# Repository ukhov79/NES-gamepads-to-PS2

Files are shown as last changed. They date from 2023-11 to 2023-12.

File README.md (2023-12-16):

# NES gamepads via PS2 interface
Connecting 8-bit NES gamepads to retrocomputer emulators or old PC via the PS2 interface

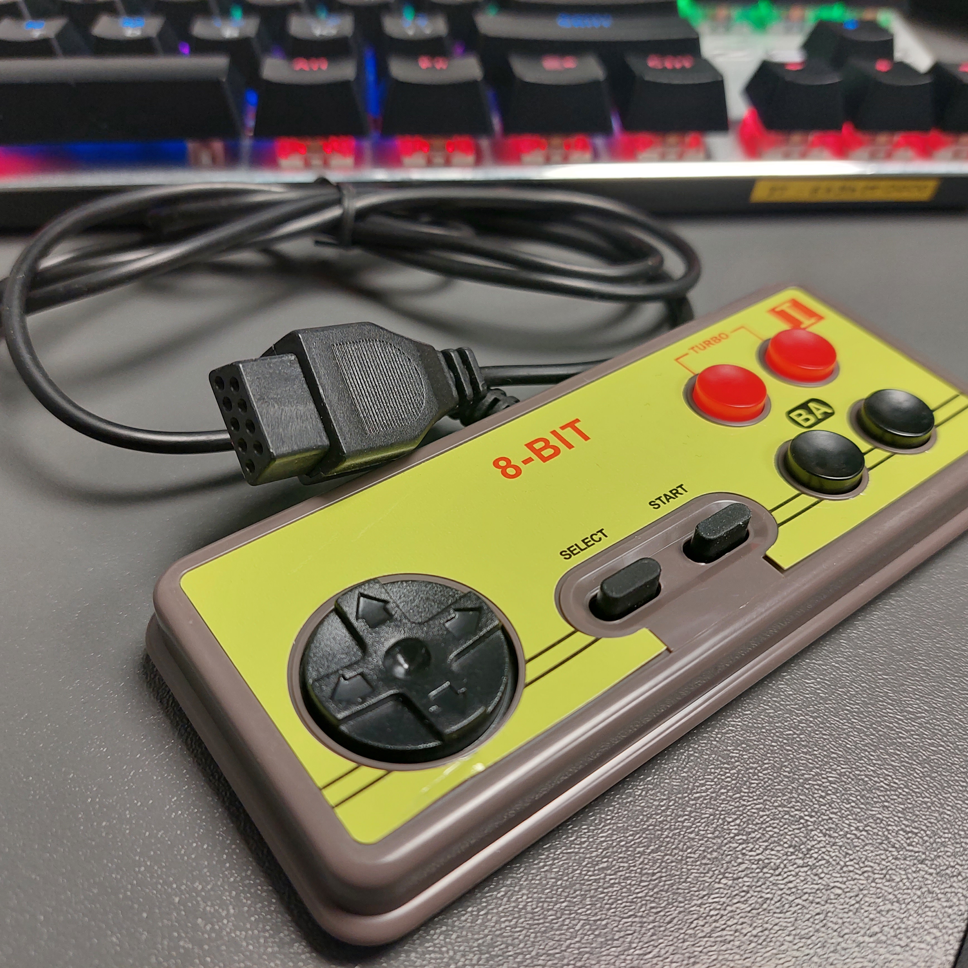
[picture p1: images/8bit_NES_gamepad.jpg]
NES Gamepad
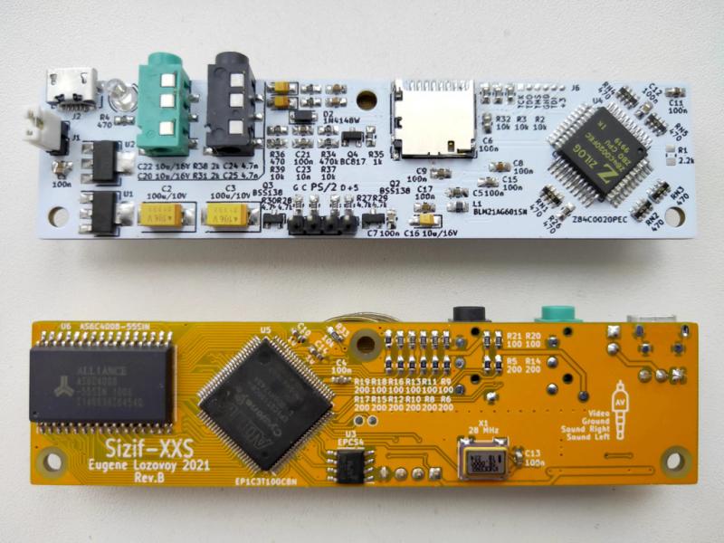
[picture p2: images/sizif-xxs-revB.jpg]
Sizif XXS retro PC emulator
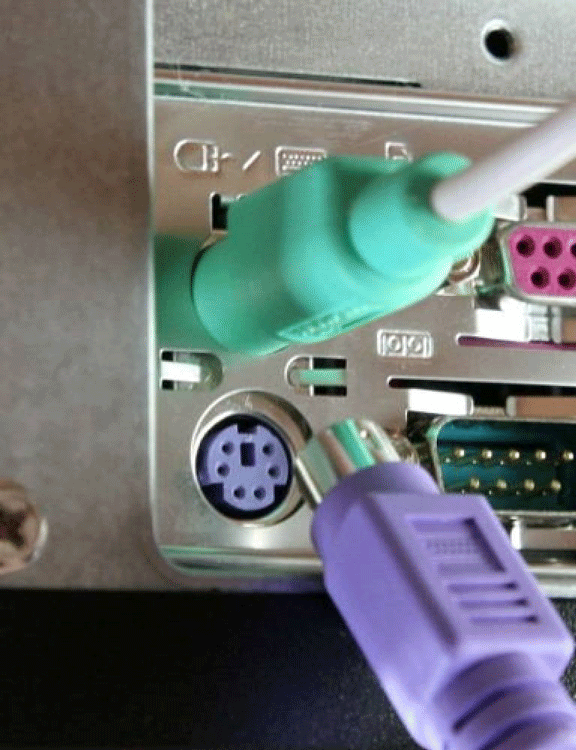
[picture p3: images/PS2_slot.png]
PS/2 slot
  

## Motivation
There are a number of good old ZX Spectrum emulator projects on the network, for example: **[Sizif XXS](https://github.com/UzixLS/zx-sizif-xxs)**. In addition, some older computers and laptops contain a PS/2 slot, but do not have the ability to connect a gamepad. The available solutions that I managed to find are either sold for money, or do not work. Therefore, it was decided to make a simple and cheap device for connecting two gamepads and PS/2 keyboard to one input of the PS/2 retro computer.

## Components
Retro PC emulator:
- Sizif XXS RevB as emulator (optional - all 3D models were designed for it) ([`Image1`](/images/sizif-xxs-revB.jpg))
- PS/2 Keyboard
- Video Cable (Jack 3.5: 1-AudioLeft, 2-AudioRight, 3-GND, 4-Video)
- 2 NES Gamepads from Sega 9pin ;)

The following purchased components will be needed to assemble the device:
- Arduino Nano V3.0 CH340 USB TYPE-C ([`Image1`](/images/Arduino-Nano-V3_0-CH340-USB_TYPE-C.png))
- PS2 MDC/S Terminal Mini Socket ([`Image1`](/images/PC2-MDC-S1.png), [`Image2`](/images/PC2-MDC-S2.png))
- Sega MD2 9Pin 90Degree Female Socket Connector ([`Image1`](/images/Sega-slot.png)), ([`Image2`](/images/Sega-slot2.png))
- 10mm Metal Button Switch Self-locking with LED 3-6V ([`Image1`](/images/Metal-Button-Switch.png), [`Image2`](/images/Metal-Button-Switch2.png))
- Screw M2.5x6mm - 13 pcs ([`Image1`](/images/M2_5x6mm.png))

For 3D modeling, I used SolidWorks. All models can be found in the 3D models directory.\
To print parts from PLA plastic, you will need an FDM 3D printer. All models are optimized for 0.4mm nozzle and 0.2mm layer thickness.

Case for Sizif XXS RevB looks like here:\
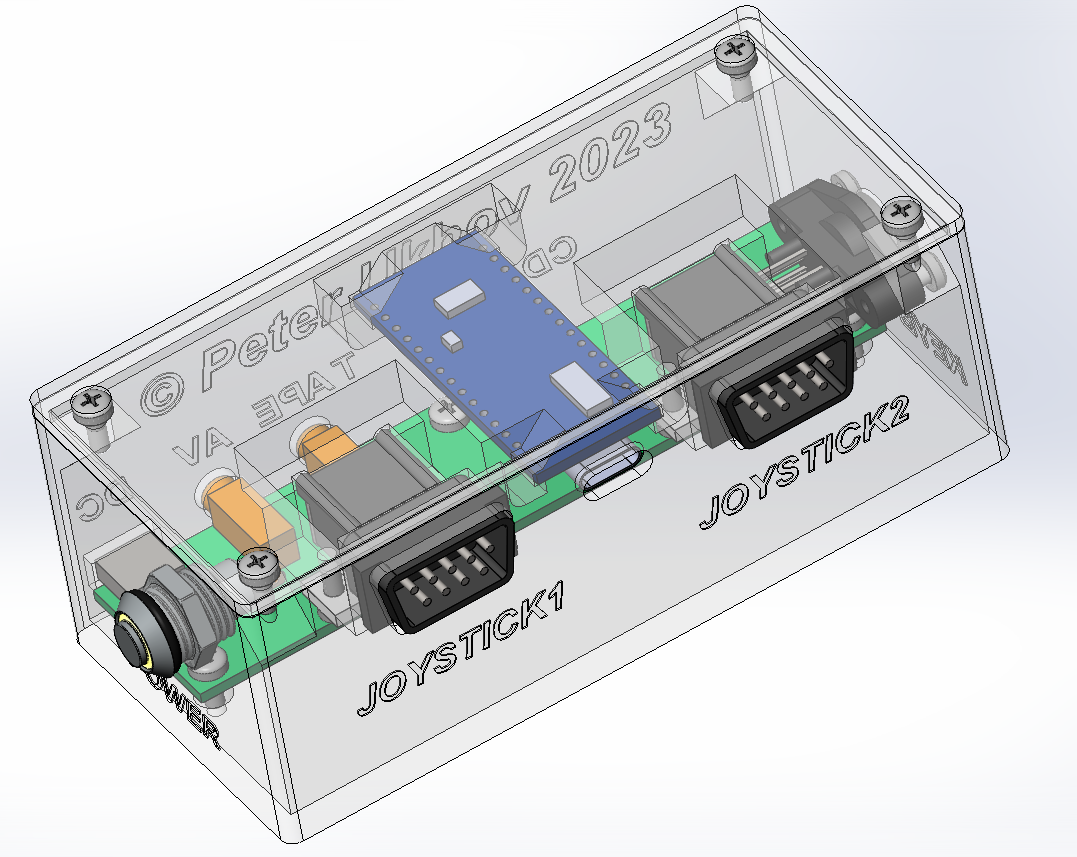
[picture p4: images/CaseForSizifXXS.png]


## Wire Diagram
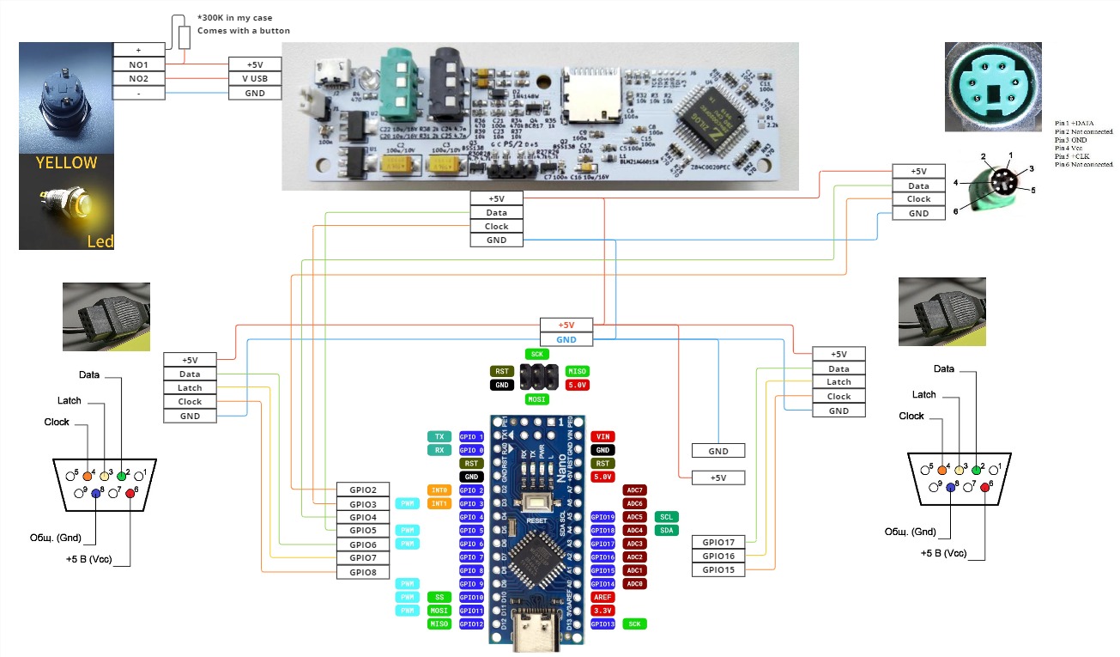
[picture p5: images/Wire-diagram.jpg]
Wire diagram


Gamepads Arduino pins:
- PULT1_DATA_PIN 17
- PULT1_LATCH_PIN 16
- PULT1_CLOCK_PIN 15
- PULT2_DATA_PIN 6
- PULT2_LATCH_PIN 7
- PULT2_CLOCK_PIN 8

Emulator Arduino pins to connect into retro PC
- SIZIF_KEYBOARD_DATA_PIN 5
- SIZIF_KEYBOARD_CLOCK_PIN 3

PS2 Keyboard Arduino pins to connect into Keyboard
- PS2_KEYBOARD_DATA_PIN 4
- PS2_KEYBOARD_CLOCK_PIN 2

For other NES sockets:

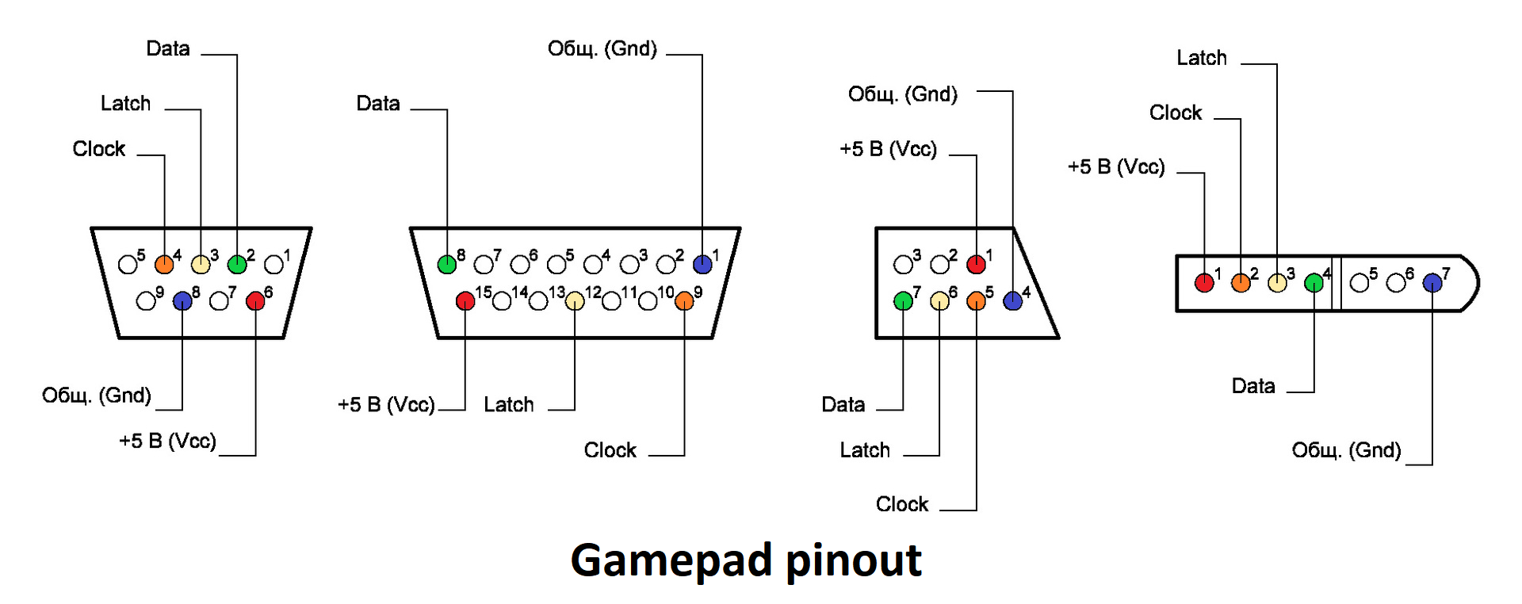
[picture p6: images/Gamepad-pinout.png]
Gamepad pinout


## Assembly instructions
First assemble the cover with the NES connectors:

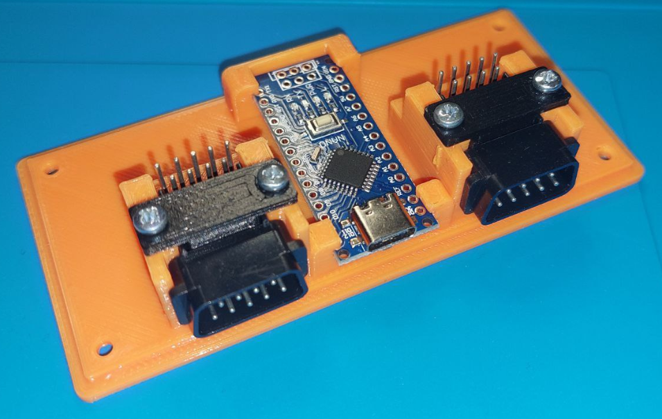
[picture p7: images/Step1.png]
Step1


Attach Sizif XXS to the case. Solder connector and resistor to the power button:

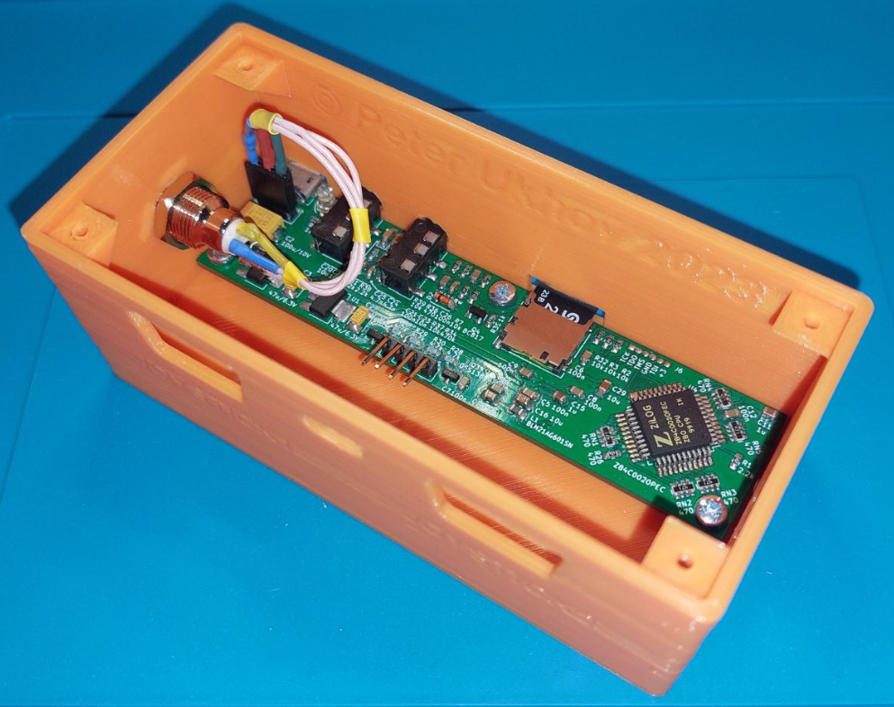
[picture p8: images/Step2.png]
Step2


Solder the wires to the NES connectors, Sizif XXS board connector and PS/2 keyboard connector:

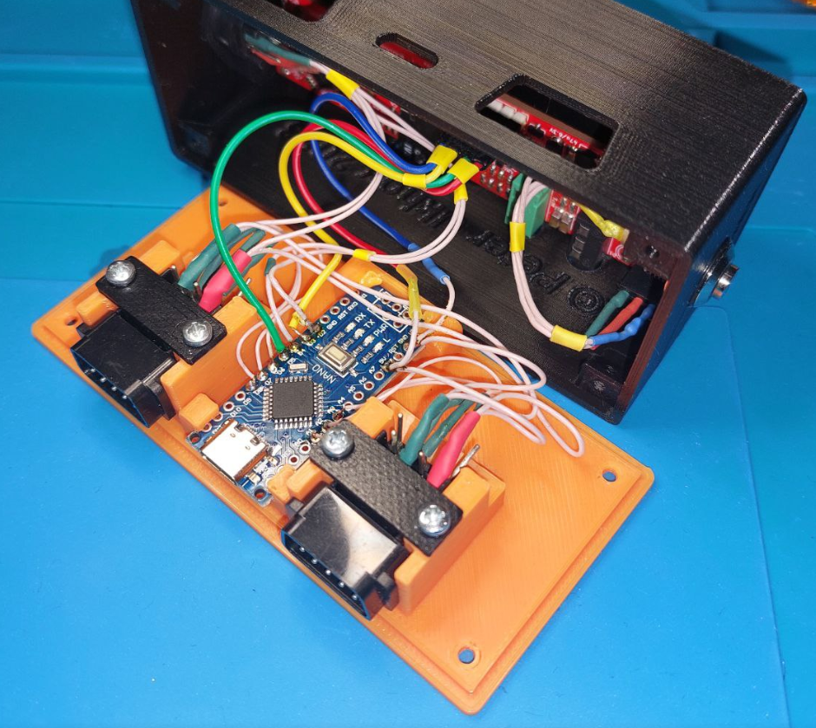
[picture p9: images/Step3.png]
Step3


Connect all connectors and close the device case:

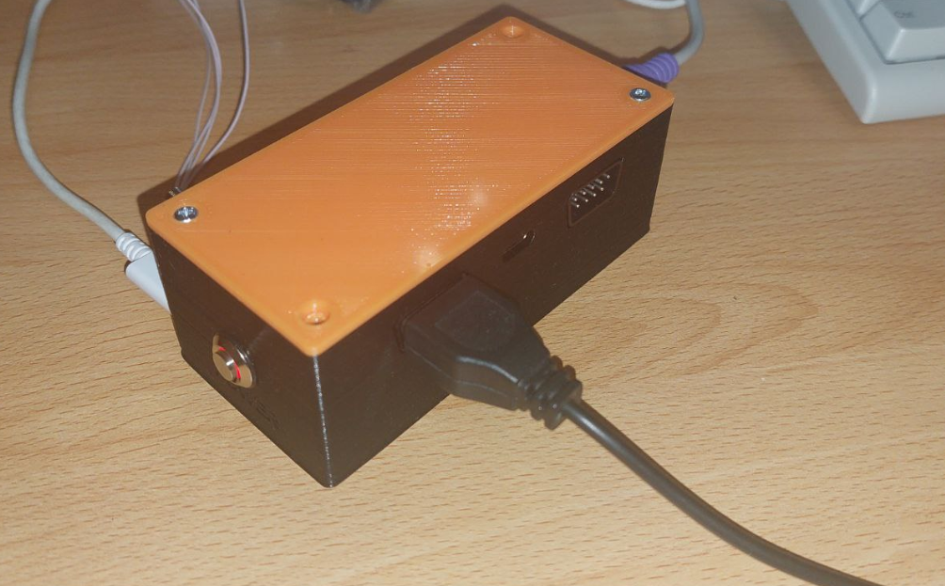
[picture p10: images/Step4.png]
Step4


During debugging, this bug appeared on one SizifXXS board:

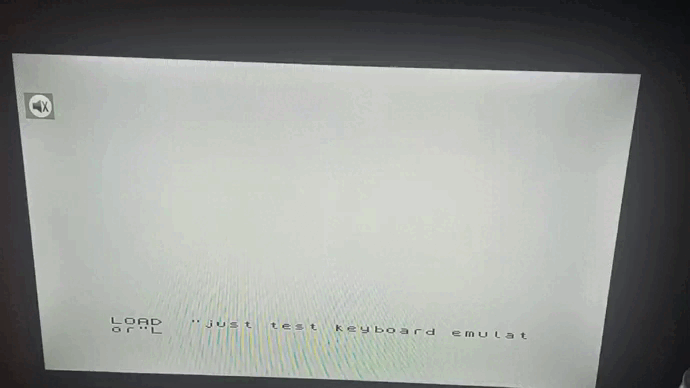
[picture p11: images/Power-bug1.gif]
Gif bug


The issue is most likely caused by an unstable power supply.
A capacitor with a larger capacity is installed on the second board and there was no problem.

## MVP demo
You can already play!

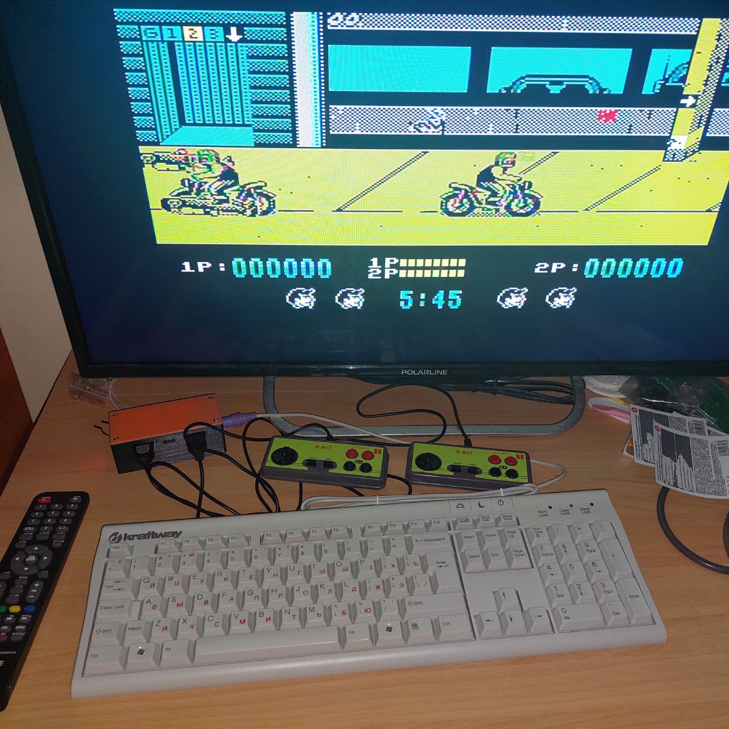
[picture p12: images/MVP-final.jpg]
MVP final view


Now it works correct for my games, like [`Seraphima`](https://zxart.ee/eng/software/game/arcade/adventure/seraphima/),
[`The Sword of IANNA`](https://spectrumcomputing.co.uk/entry/30447/ZX-Spectrum/The_Sword_of_IANNA)
and many others...
For two players it works good for [`Target Renegade`](https://spectrumcomputing.co.uk/entry/4087/ZX-Spectrum/Target_Renegade).

An example for a simple game where the Gamepad already works well ;)

Game: [`Earth Shaker`](https://viva-games.ru/game/earth-shaker)

Gif bug

## TODO list
- [X] Create TODO list
- [X] 3D Case model for Sizif XXS
- [X] Collect needed components and write description
- [X] Buy all components to refine models
- [X] Create Wire Diagram
- [X] 3D Printing and Assembly Test
- [X] Final Rebuild Case model for Sizif XXS and all components
- [X] Assemble the device
- [X] Write about power bug
- [X] Code and test Keyboard repiter
- [X] Code MVP with hardcoded keys
- [X] Test for two NES Gamepads
- [ ] Rewrite source code to eliminate key-repeat bugs (rare, but annoying)
- [ ] Add NES class with buffer
- [ ] Rewrite code for keyboard libs (not optimal, it should be one lib)
- [X] Add good key handling for NES Joystick (simultaneous pressing)
- [ ] Add Configuration using NumLock key and EEPROM
- [ ] Create Video Guide
- [X] Enjoy local multiplayer Games on Sizif XXS

## References
### Ideas
- Project from Volo: Volo's Gamepad to PS/2 Adapter [`Video`](https://www.youtube.com/watch?v=FsssOJsSnDY)
- Project from GameStar: Dynapoint GameStar: 1993 NES to PC Keyboard Adapter [`Video`](https://youtu.be/Ko1SEP-VtGs?si=I_s7tsCCiQifjQXr)

### Arduino Projects
- NES Controller Interface with an Arduino UNO - Projects [`Page`](https://www.allaboutcircuits.com/projects/nes-controller-interface-with-an-arduino-uno/)
- Arduino ps2dev library [`code`](https://github.com/Harvie/ps2dev)
- nes_gamepad_adapter [`code`](https://github.com/Kokorev92/nes_gamepad_adapter/tree/master)
- PS/2 Arduino Keyboard [`code`](https://github.com/techpaul/PS2KeyAdvanced)
- How To Save Values On Arduino With EEPROM [`Page`](https://roboticsbackend.com/how-to-save-values-on-arduino-with-eeprom/)

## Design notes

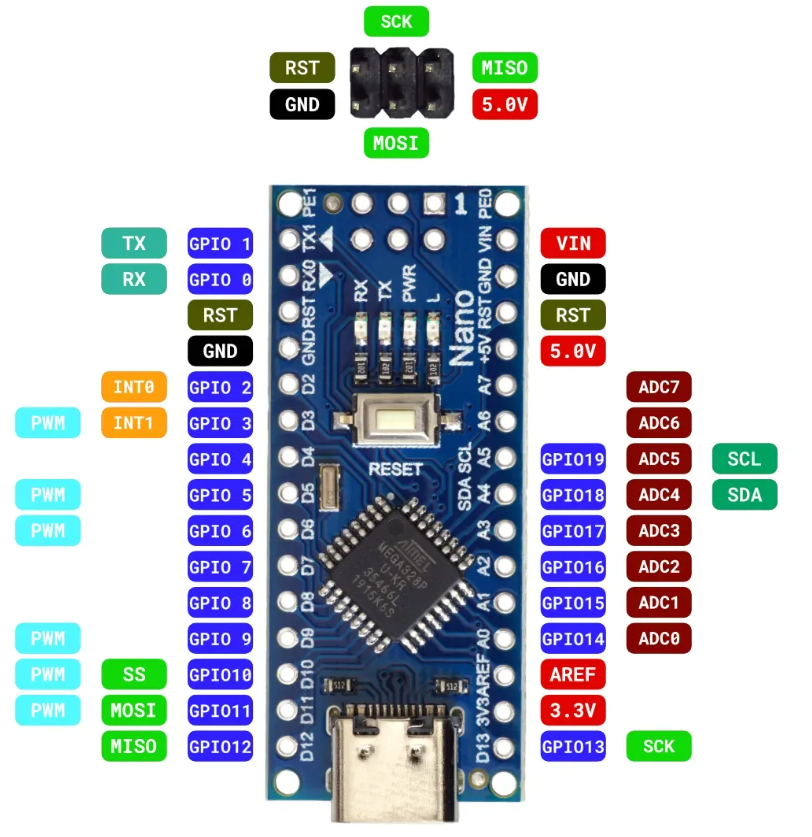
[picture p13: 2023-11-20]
images/Arduino-Nano-pinout.png

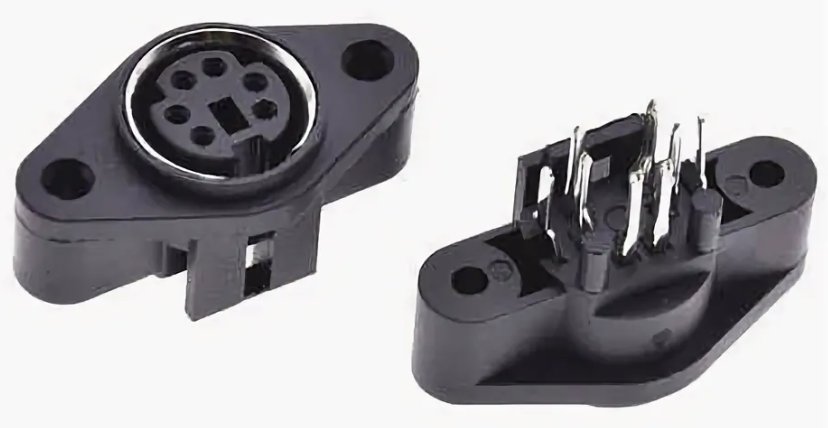
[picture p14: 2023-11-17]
images/PC2-MDC-S1.png

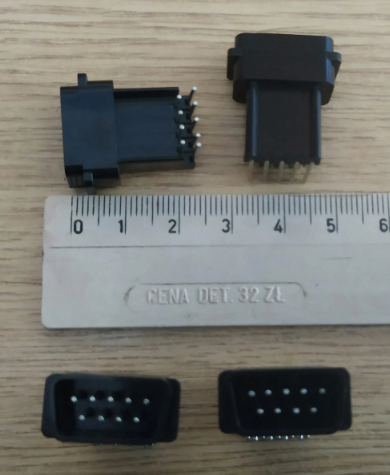
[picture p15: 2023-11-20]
images/Sega-slot2.png

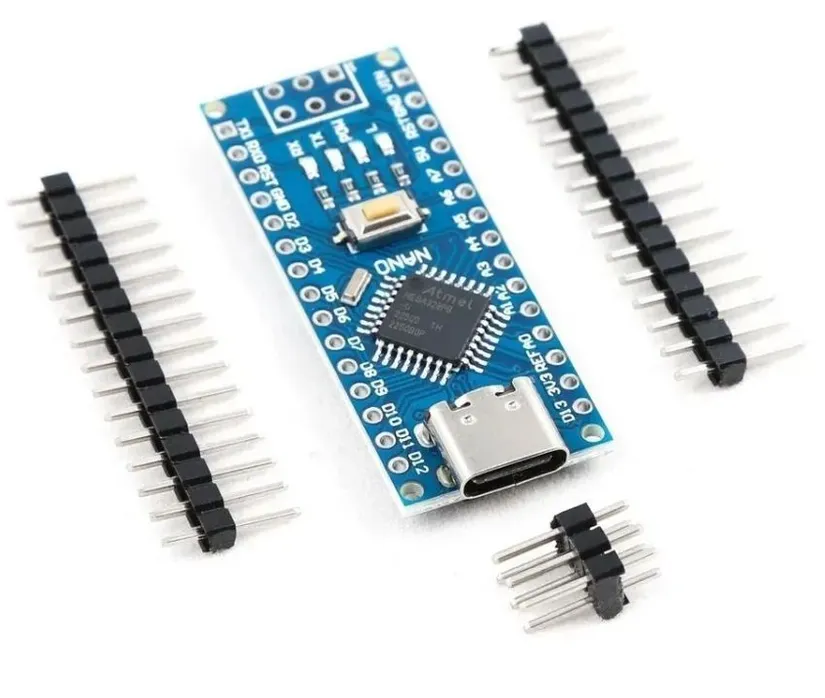
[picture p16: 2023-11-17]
images/Arduino-Nano-V3_0-CH340-USB_TYPE-C.png

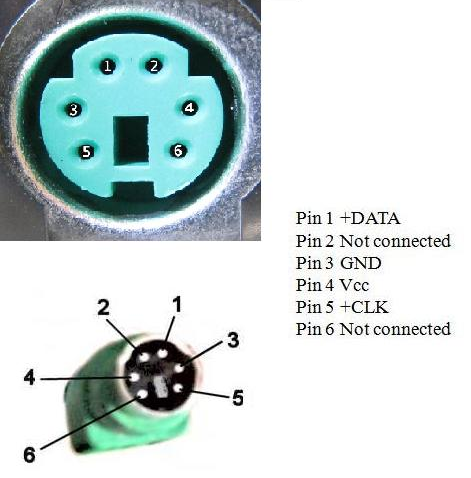
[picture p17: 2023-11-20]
images/Pin-Out-PS2-Male-Female-Connectors.png

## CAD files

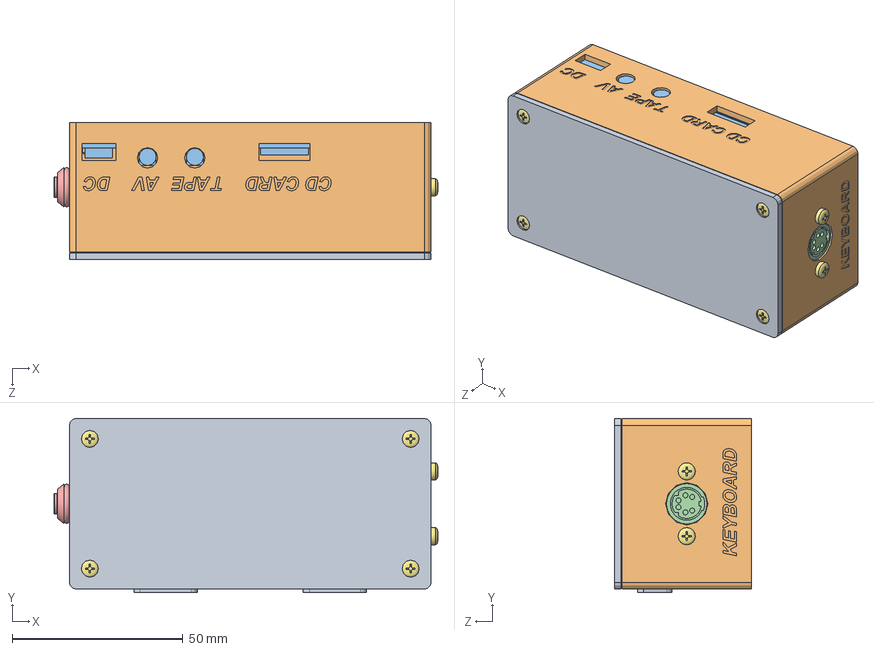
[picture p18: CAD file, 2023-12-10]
3Dmodels/Case_assembly.SLDASM
112.5 x 51.0 x 40.2 mm
Case1
PCB_Sizif_XXS
PS2_socket
Metal-Self-Lock-Switch-M10
Button-nut
Case2
M2_5x06 x 13
arduino_nano
NES-Slot x 2
NES-Fix x 2

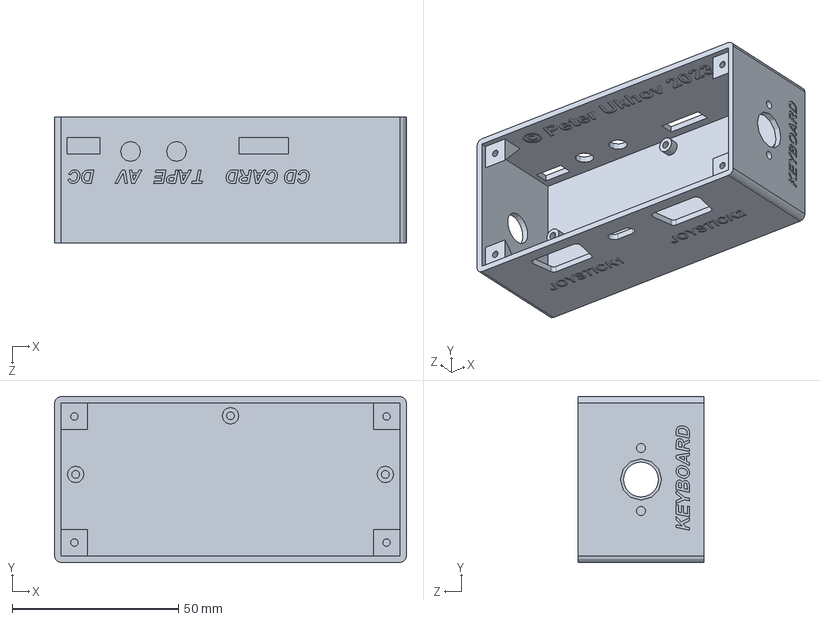
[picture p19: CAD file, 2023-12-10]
3Dmodels/Case1.SLDPRT
106.0 x 50.0 x 38.0 mm

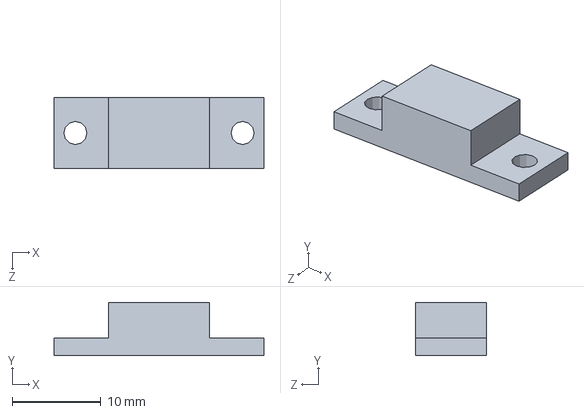
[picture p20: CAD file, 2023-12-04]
3Dmodels/NES-Fix.SLDPRT
23.6 x 6.00 x 8.00 mm

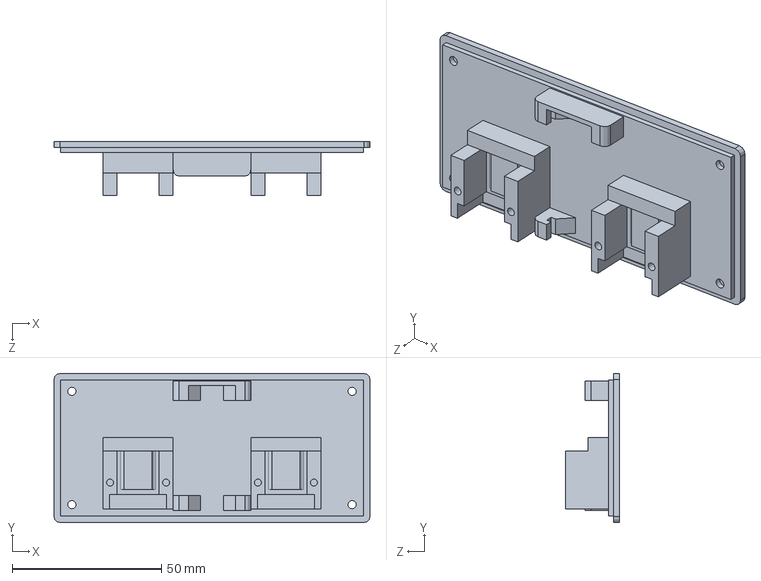
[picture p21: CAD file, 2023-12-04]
3Dmodels/Case2.SLDPRT
106.0 x 50.0 x 18.1 mm

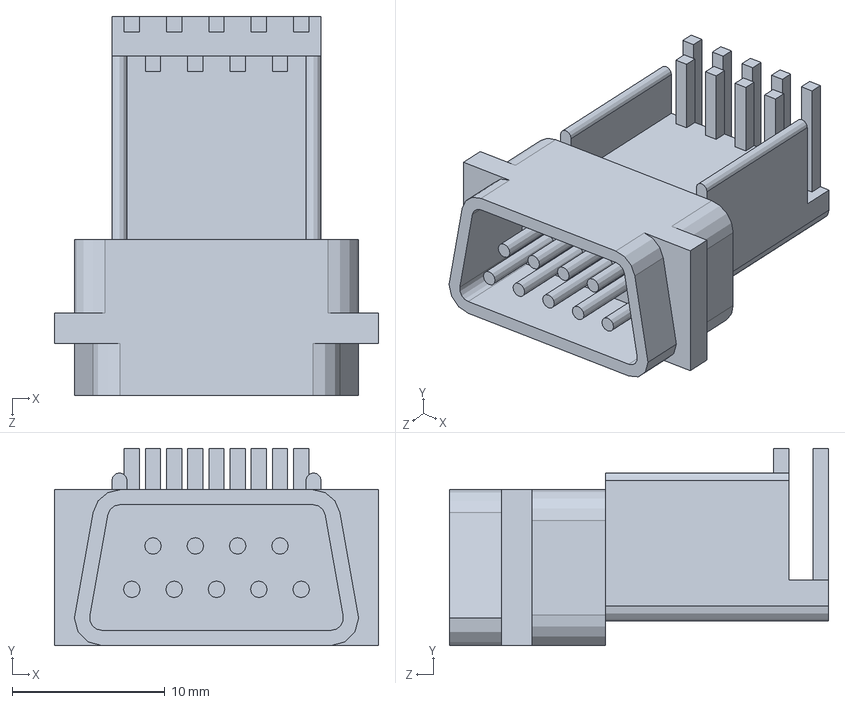
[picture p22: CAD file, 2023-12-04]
3Dmodels/NES-Slot.SLDPRT
21.2 x 12.9 x 24.8 mm

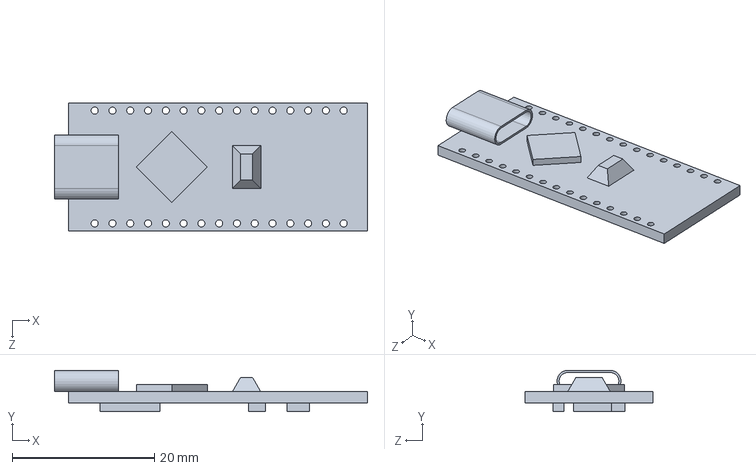
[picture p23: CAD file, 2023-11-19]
3Dmodels/arduino_nano.SLDPRT
44.0 x 5.80 x 18.0 mm

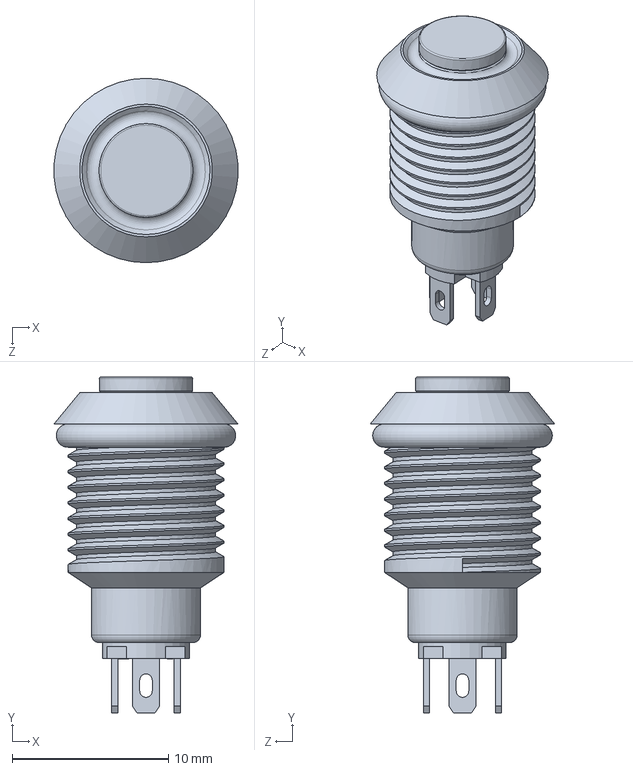
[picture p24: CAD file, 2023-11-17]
3Dmodels/Metal-Self-Lock-Switch-M10.SLDPRT
11.8 x 21.5 x 11.8 mm

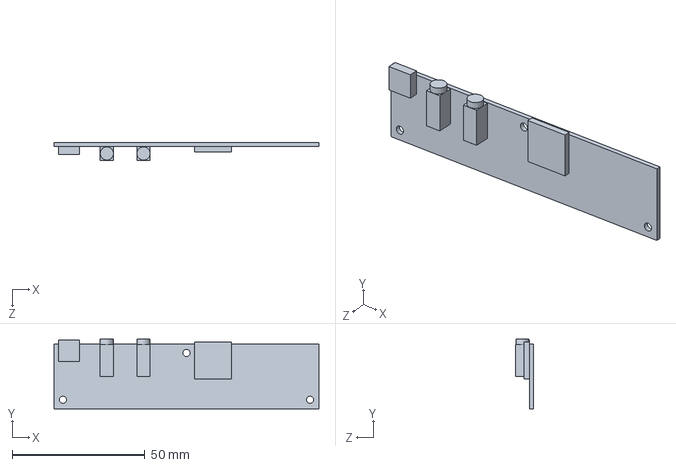
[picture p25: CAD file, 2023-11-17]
3Dmodels/PCB_Sizif_XXS.SLDPRT
100.0 x 26.3 x 6.70 mm

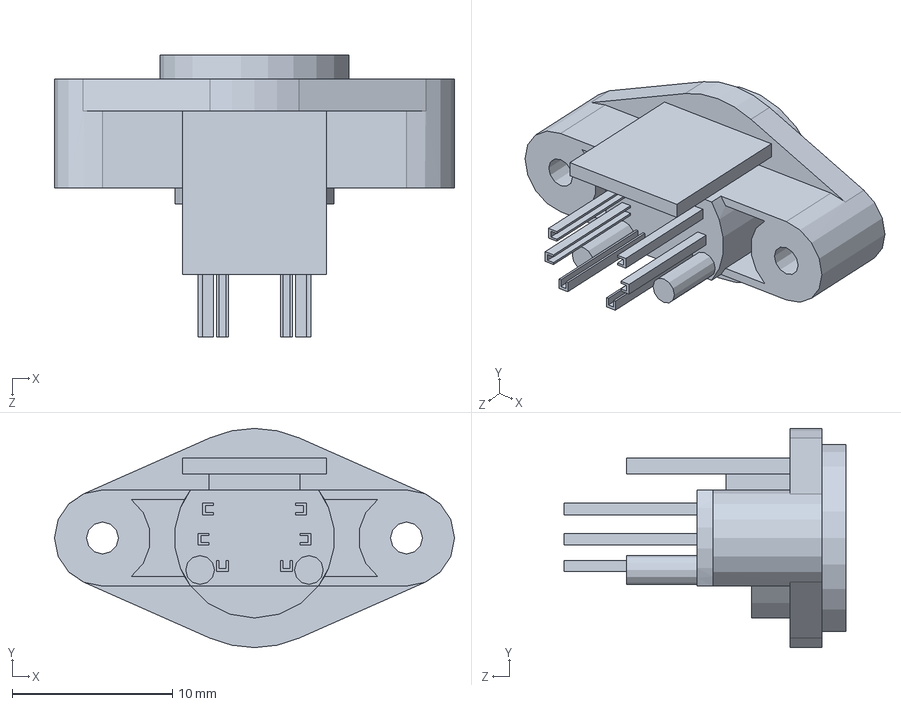
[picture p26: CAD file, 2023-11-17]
3Dmodels/PS2_socket.SLDPRT
25.0 x 13.7 x 17.6 mm

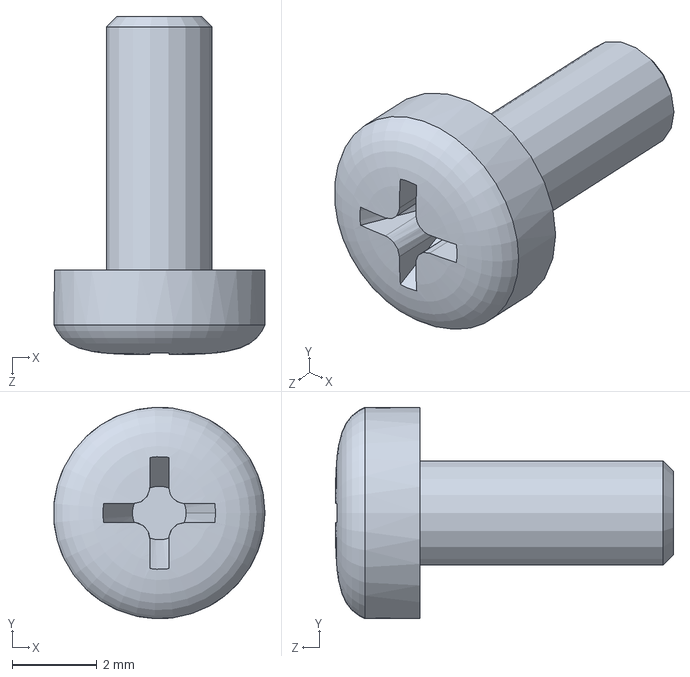
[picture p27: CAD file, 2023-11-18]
3Dmodels/M2_5x06.SLDPRT
4.99 x 4.99 x 8.00 mm

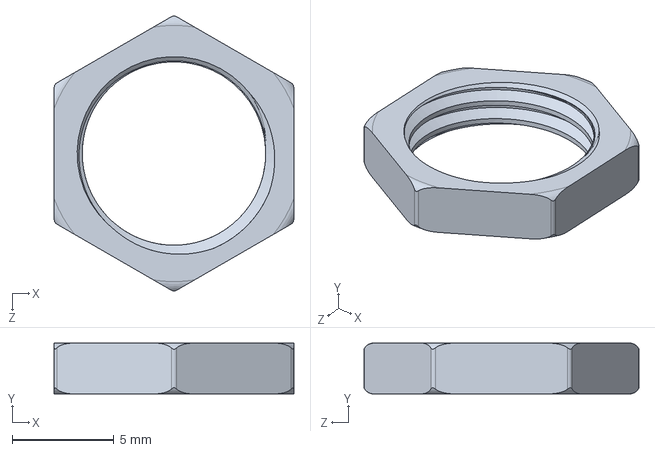
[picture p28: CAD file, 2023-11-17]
3Dmodels/Button-nut.SLDPRT
11.8 x 2.50 x 13.5 mm

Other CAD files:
3Dmodels/Case1.STL
3Dmodels/Case2.STL
3Dmodels/NES-Fix.STL

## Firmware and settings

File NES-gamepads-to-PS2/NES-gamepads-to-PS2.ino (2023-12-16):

/*
================================================================================
   Notes
================================================================================

    Clock pins for PS/2 and SizifXXS should be irq pins.
    It works now, but the code needs to be reworked!
    TODO: 
    1. Rewrite lib PS2keyAdvanced and ps2dev to repetier
    2. Add classes for NES with buffers and statuses
*/
//===============================================================================
//  Connections
//===============================================================================

// Gamepads pins
#define PULT1_DATA_PIN 17
#define PULT1_LATCH_PIN 16
#define PULT1_CLOCK_PIN 15
#define PULT2_DATA_PIN 6
#define PULT2_LATCH_PIN 7
#define PULT2_CLOCK_PIN 8

// Emulator pins to connect into retro PC
#define SIZIF_KEYBOARD_DATA_PIN 5
#define SIZIF_KEYBOARD_CLOCK_PIN 3

// PS2 Keyboard pins to connect into Keyboard
#define PS2_KEYBOARD_DATA_PIN 4
#define PS2_KEYBOARD_CLOCK_PIN 2

// Time countdown for delay in polling cycles of gamepads
#define TICK 2

// var to read PS/2 kodes
uint16_t PS2_d;

#define PS2_REQUIRES_PROGMEM 1

//===============================================================================
//  Gamepads class
//===============================================================================

struct pult_cfg {
  int data;
  int latch;
  int clock;
};

pult_cfg pult_1 = {
  .data = PULT1_DATA_PIN,
  .latch = PULT1_LATCH_PIN,
  .clock = PULT1_CLOCK_PIN
};

pult_cfg pult_2 = {
  .data = PULT2_DATA_PIN,
  .latch = PULT2_LATCH_PIN,
  .clock = PULT2_CLOCK_PIN
};

void init_joystick(pult_cfg& cfg) {
  pinMode(cfg.data, INPUT_PULLUP);
  pinMode(cfg.clock, OUTPUT);
  pinMode(cfg.latch, OUTPUT);
  digitalWrite(cfg.clock, HIGH);
}

int get_keys_state_joystick(pult_cfg& cfg) {
  digitalWrite(cfg.latch, HIGH);
  delayMicroseconds(TICK);
  digitalWrite(cfg.latch, LOW);

  int keys_state = 0;

  for (int i = 0; i < 8; ++i) {
    delayMicroseconds(TICK);
    digitalWrite(cfg.clock, LOW);

    keys_state <<= 1;
    keys_state += digitalRead(cfg.data);

    delayMicroseconds(TICK);
    digitalWrite(cfg.clock, HIGH);
  }

  return keys_state;
}

int pult_1_keys = 0;
int pult_2_keys = 0;

// The order of shifting for the buttons:
// 0 - Right, 1 - Left, 2 - Down, 3 - Up, 4 - Start, 5 - Select, 6 - B, 7 - A
// Codes for keyboard Joystick
// OPQA Joystick
byte keys_pult_1_c[] = {0x4D, 0x44, 0x1C, 0x15, 0x5A, 0x29, 0x43, 0x29};
// Sizif Joystick - Numpad
byte keys_pult_2_c[] = {0x22, 0x1A, 0x3A, 0x42, 0x5A, 0x29, 0x21, 0x2A};

// TODO: Read from EEPROM, will be configured, change keycodes

//===============================================================================
//  libraries:
//  To Read keys from PS/2 keyboard 
//  https://github.com/techpaul/PS2KeyAdvanced
//  To Emulate PS/2 Keyboard
//  https://github.com/Harvie/ps2dev
//===============================================================================

#include <EEPROM.h>
#include <PS2KeyAdvanced.h>
#include <ps2dev.h>

PS2dev keyboard(SIZIF_KEYBOARD_CLOCK_PIN, SIZIF_KEYBOARD_DATA_PIN);
PS2KeyAdvanced PS2keyboard;

//===============================================================================
//  Keyboard emulator keys - emul.cpp
//===============================================================================

int enabled = 0; // pseudo variable for state of "keyboard"

// Map codes to keys
// For keyboard repetier
const uint16_t key_codes[][4] = {
  { 0x115,  0xE0, 0x6B, 0x00 }, { 0x8115, 0xE0, 0xF0, 0x6B }, // LEFT
  { 0x116,  0xE0, 0x74, 0x00 }, { 0x8116, 0xE0, 0xF0, 0x74 }, // RIGHT
  { 0x117,  0xE0, 0x75, 0x00 }, { 0x8117, 0xE0, 0xF0, 0x75 }, // UP
  { 0x118,  0xE0, 0x72, 0x00 }, { 0x8118, 0xE0, 0xF0, 0x72 }, // DOWN
  { 0x11B,  0x76, 0x00, 0x00 }, { 0x811B, 0xF0, 0x76, 0x00 }, // ESC
  { 0x161,  0x05, 0x00, 0x00 }, { 0x8161, 0xF0, 0x05, 0x00 }, // F1
  { 0x162,  0x06, 0x00, 0x00 }, { 0x8162, 0xF0, 0x06, 0x00 }, // F2
  { 0x163,  0x04, 0x00, 0x00 }, { 0x8163, 0xF0, 0x04, 0x00 }, // F3
  { 0x164,  0x0c, 0x00, 0x00 }, { 0x8164, 0xF0, 0x0c, 0x00 }, // F4
  { 0x165,  0x03, 0x00, 0x00 }, { 0x8165, 0xF0, 0x03, 0x00 }, // F5
  { 0x166,  0x0b, 0x00, 0x00 }, { 0x8166, 0xF0, 0x0b, 0x00 }, // F6
  { 0x167,  0x83, 0x00, 0x00 }, { 0x8167, 0xF0, 0x83, 0x00 }, // F7
  { 0x168,  0x0a, 0x00, 0x00 }, { 0x8168, 0xF0, 0x0a, 0x00 }, // F8
  { 0x169,  0x01, 0x00, 0x00 }, { 0x8169, 0xF0, 0x01, 0x00 }, // F9
  { 0x16A,  0x09, 0x00, 0x00 }, { 0x816A, 0xF0, 0x09, 0x00 }, // F10
  { 0x16B,  0x78, 0x00, 0x00 }, { 0x816B, 0xF0, 0x78, 0x00 }, // F11
  { 0x16C,  0x07, 0x00, 0x00 }, { 0x816C, 0xF0, 0x07, 0x00 }, // F12
  { 0x40,   0x0e, 0x00, 0x00 }, { 0x8040, 0xF0, 0x0e, 0x00 }, // ACCENT
  { 0x31,   0x16, 0x00, 0x00 }, { 0x8031, 0xF0, 0x16, 0x00 }, // 1
  { 0x32,   0x1e, 0x00, 0x00 }, { 0x8032, 0xF0, 0x1e, 0x00 }, // 2
  { 0x33,   0x26, 0x00, 0x00 }, { 0x8033, 0xF0, 0x26, 0x00 }, // 3
  { 0x34,   0x25, 0x00, 0x00 }, { 0x8034, 0xF0, 0x25, 0x00 }, // 4
  { 0x35,   0x2e, 0x00, 0x00 }, { 0x8035, 0xF0, 0x2e, 0x00 }, // 5
  { 0x36,   0x36, 0x00, 0x00 }, { 0x8036, 0xF0, 0x36, 0x00 }, // 6
  { 0x37,   0x3d, 0x00, 0x00 }, { 0x8037, 0xF0, 0x3d, 0x00 }, // 7
  { 0x38,   0x3e, 0x00, 0x00 }, { 0x8038, 0xF0, 0x3e, 0x00 }, // 8
  { 0x39,   0x46, 0x00, 0x00 }, { 0x8039, 0xF0, 0x46, 0x00 }, // 9
  { 0x30,   0x45, 0x00, 0x00 }, { 0x8030, 0xF0, 0x45, 0x00 }, // 0
  { 0x3C,   0x4e, 0x00, 0x00 }, { 0x803C, 0xF0, 0x4e, 0x00 }, // -
  { 0x5F,   0x55, 0x00, 0x00 }, { 0x805F, 0xF0, 0x55, 0x00 }, // =
  { 0x11C,  0x66, 0x00, 0x00 }, { 0x811C, 0xF0, 0x66, 0x00 }, // BACKSPACE
  { 0x11D,  0x0d, 0x00, 0x00 }, { 0x811D, 0xF0, 0x0d, 0x00 }, // TAB
  { 0x51,   0x15, 0x00, 0x00 }, { 0x8051, 0xF0, 0x15, 0x00 }, // Q
  { 0x57,   0x1d, 0x00, 0x00 }, { 0x8057, 0xF0, 0x1d, 0x00 }, // W
  { 0x45,   0x24, 0x00, 0x00 }, { 0x8045, 0xF0, 0x24, 0x00 }, // E
  { 0x52,   0x2d, 0x00, 0x00 }, { 0x8052, 0xF0, 0x2d, 0x00 }, // R
  { 0x54,   0x2c, 0x00, 0x00 }, { 0x8054, 0xF0, 0x2c, 0x00 }, // T
  { 0x59,   0x35, 0x00, 0x00 }, { 0x8059, 0xF0, 0x35, 0x00 }, // Y
  { 0x55,   0x3c, 0x00, 0x00 }, { 0x8055, 0xF0, 0x3c, 0x00 }, // U
  { 0x49,   0x43, 0x00, 0x00 }, { 0x8049, 0xF0, 0x43, 0x00 }, // I
  { 0x4F,   0x44, 0x00, 0x00 }, { 0x804F, 0xF0, 0x44, 0x00 }, // O
  { 0x50,   0x4d, 0x00, 0x00 }, { 0x8050, 0xF0, 0x4d, 0x00 }, // P
  { 0x5D,   0x54, 0x00, 0x00 }, { 0x805D, 0xF0, 0x54, 0x00 }, // OPEN_BRACKET
  { 0x5E,   0x5b, 0x00, 0x00 }, { 0x805E, 0xF0, 0x5b, 0x00 }, // CLOSE_BRACKET
  { 0x11E,  0x5a, 0x00, 0x00 }, { 0x811E, 0xF0, 0x5a, 0x00 }, // ENTER
  { 0x1103, 0x58, 0xF0, 0x58 }, { 0x8103, 0x58, 0xF0, 0x58 }, // CAPS_LOCK on/off 
  { 0x41,   0x1c, 0x00, 0x00 }, { 0x8041, 0xF0, 0x1c, 0x00 }, // A
  { 0x53,   0x1b, 0x00, 0x00 }, { 0x8053, 0xF0, 0x1b, 0x00 }, // S
  { 0x44,   0x23, 0x00, 0x00 }, { 0x8044, 0xF0, 0x23, 0x00 }, // D
  { 0x46,   0x2b, 0x00, 0x00 }, { 0x8046, 0xF0, 0x2b, 0x00 }, // F
  { 0x47,   0x34, 0x00, 0x00 }, { 0x8047, 0xF0, 0x34, 0x00 }, // G
  { 0x48,   0x33, 0x00, 0x00 }, { 0x8048, 0xF0, 0x33, 0x00 }, // H
  { 0x4A,   0x3b, 0x00, 0x00 }, { 0x804A, 0xF0, 0x3b, 0x00 }, // J
  { 0x4B,   0x42, 0x00, 0x00 }, { 0x804B, 0xF0, 0x42, 0x00 }, // K
  { 0x4C,   0x4b, 0x00, 0x00 }, { 0x804C, 0xF0, 0x4b, 0x00 }, // L
  { 0x5B,   0x4c, 0x00, 0x00 }, { 0x805B, 0xF0, 0x4c, 0x00 }, // ; SEMI_COLON
  { 0x3A,   0x52, 0x00, 0x00 }, { 0x803A, 0xF0, 0x52, 0x00 }, // TICK_MARK
  { 0x5C,   0x5d, 0x00, 0x00 }, { 0x805C, 0xF0, 0x5d, 0x00 }, // BACKSLASH
  { 0x4106, 0x12, 0x00, 0x00 }, { 0x8106, 0xF0, 0x12, 0x00 }, // LEFT_SHIFT
  { 0x5A,   0x1a, 0x00, 0x00 }, { 0x805A, 0xF0, 0x1a, 0x00 }, // Z
  { 0x58,   0x22, 0x00, 0x00 }, { 0x8058, 0xF0, 0x22, 0x00 }, // X
  { 0x43,   0x21, 0x00, 0x00 }, { 0x8043, 0xF0, 0x21, 0x00 }, // C
  { 0x56,   0x2a, 0x00, 0x00 }, { 0x8056, 0xF0, 0x2a, 0x00 }, // V
  { 0x42,   0x32, 0x00, 0x00 }, { 0x8042, 0xF0, 0x32, 0x00 }, // B
  { 0x4E,   0x31, 0x00, 0x00 }, { 0x804E, 0xF0, 0x31, 0x00 }, // N
  { 0x4D,   0x3a, 0x00, 0x00 }, { 0x804D, 0xF0, 0x3a, 0x00 }, // M
  { 0x3B,   0x41, 0x00, 0x00 }, { 0x803B, 0xF0, 0x41, 0x00 }, // , COMMA
  { 0x3D,   0x49, 0x00, 0x00 }, { 0x803D, 0xF0, 0x49, 0x00 }, // . PERIOD
  { 0x3E,   0x4a, 0x00, 0x00 }, { 0x803E, 0xF0, 0x4a, 0x00 }, // SLASH
  { 0x4107, 0x59, 0x00, 0x00 }, { 0x8107, 0xF0, 0x59, 0x00 }, // RIGHT_SHIFT
  { 0x2108, 0x14, 0x00, 0x00 }, { 0x8108, 0xF0, 0x14, 0x00 },	// LEFT_CONTROL
	{ 0x90A,  0x11, 0x00, 0x00 }, { 0x810A, 0xF0, 0x11, 0x00 },	// LEFT_ALT
	{ 0x101,  0x77, 0xF0, 0x77 }, { 0x8101, 0x77, 0xF0, 0x77 },	// NUM_LOCK on/off
			// ASTERISK = 0x7c,
			// NUMPAD_MINUS = 0x7b,
	{ 0x27,   0x6c, 0x00, 0x00 }, { 0x8027, 0xF0, 0x6c, 0x00 },	// NUMPAD_SEVEN,
	{ 0x28,   0x75, 0x00, 0x00 }, { 0x8028, 0xF0, 0x75, 0x00 },	// NUMPAD_EIGHT,
	{ 0x29,   0x7d, 0x00, 0x00 }, { 0x8029, 0xF0, 0x7d, 0x00 },	// NUMPAD_NINE,
			// PLUS = 0x79,
	{ 0x24,   0x6b, 0x00, 0x00 }, { 0x8024, 0xF0, 0x6b, 0x00 },	// NUMPAD_FOUR,
	{ 0x25,   0x73, 0x00, 0x00 }, { 0x8025, 0xF0, 0x73, 0x00 },	// NUMPAD_FIVE,
	{ 0x26,   0x74, 0x00, 0x00 }, { 0x8026, 0xF0, 0x74, 0x00 },	// NUMPAD_SIX,
	{ 0x21,   0x69, 0x00, 0x00 }, { 0x8021, 0xF0, 0x69, 0x00 },	// NUMPAD_ONE,
	{ 0x22,   0x72, 0x00, 0x00 }, { 0x8022, 0xF0, 0x72, 0x00 },	// NUMPAD_TWO,
	{ 0x23,   0x73, 0x00, 0x00 }, { 0x8023, 0xF0, 0x73, 0x00 },	// NUMPAD_THREE,
	{ 0x20,   0x70, 0x00, 0x00 }, { 0x8020, 0xF0, 0x70, 0x00 },	// NUMPAD_ZERO,
			// DECIMAL = 0x71
  { 0x11F,  0x29, 0x00, 0x00 }, { 0x811F, 0xF0, 0x29, 0x00 }}; // Space

const int Key_count = sizeof(key_codes)/sizeof(uint16_t)/4;

void Sendcode(uint16_t scode) {

int send_state = -1;

  for(int i = 0; i < Key_count; i++) {
    if(key_codes[i][0] == scode) {
      do {
        send_state = keyboard.write(key_codes[i][1]);
        if (key_codes[i][2] != 0x00) send_state += keyboard.write(key_codes[i][2]);
        if (key_codes[i][3] != 0x00) send_state += keyboard.write(key_codes[i][3]);
      }
       while (send_state < 0);
    }
  }

}

void ack() {
  //acknowledge commands
  while(keyboard.write(0xFA));
}

int keyboardcommand(int command) {
  unsigned char val;
  switch (command) {
  case 0xFF: //reset
    ack();
    //the while loop lets us wait for the host to be ready
    while(keyboard.write(0xAA)!=0);
    break;
  case 0xFE: //resend
    ack();
    break;
  case 0xF6: //set defaults
    //enter stream mode
    ack();
    break;
  case 0xF5: //disable data reporting
    //FM
    enabled = 0;
    ack();
    break;
  case 0xF4: //enable data reporting
    //FM
    enabled = 1;
    ack();
    break;
  case 0xF3: //set typematic rate
    ack();
    keyboard.read(&val); //do nothing with the rate
    ack();
    break;
  case 0xF2: //get device id
    ack();
    keyboard.write(0xAB);
    keyboard.write(0x83);
    break;
  case 0xF0: //set scan code set
    ack();
    keyboard.read(&val); //do nothing with the rate
    ack();
    break;
  case 0xEE: //echo
    //ack();
    keyboard.write(0xEE);
    break;
  case 0xED: //set/reset LEDs
    ack();
    keyboard.read(&val); //do nothing with the rate
    Serial.println('Val = '+val);
    ack();
    break;
  }
}


//===============================================================================
//  Setup
//===============================================================================

void setup() {
  // send the keyboard start up to SIZIF XXS
  while(keyboard.write(0xAA)!=0);
  delay(10);

  // init for PS/2 keyboard
  PS2keyboard.begin(PS2_KEYBOARD_DATA_PIN, PS2_KEYBOARD_CLOCK_PIN);
  delay(10);

  // init Gamepads
  init_joystick(pult_1);
  init_joystick(pult_2);

  // To write debug info
  Serial.begin(9600);

}

//===============================================================================
//  loop
//===============================================================================

void loop() {

  unsigned char c;
  //if host device wants to send a command:
  if((digitalRead(SIZIF_KEYBOARD_CLOCK_PIN)==LOW) || (digitalRead(SIZIF_KEYBOARD_DATA_PIN) == LOW)) {
    while(keyboard.read(&c)) ;
    keyboardcommand(c);
  }
  else { 
    //send keypresses accordingly using scancodes
    if (PS2keyboard.available()) {
      Sendcode(PS2keyboard.read());
      // PS2_d & 0xFF - ASCII Code
      // c >> 8 - Status bits
    }

      // read Gamepads data
      int pult_1_keys2 = get_keys_state_joystick(pult_1);
      int pult_2_keys2 = get_keys_state_joystick(pult_2);

      for (int i = 0; i < 8; i++) {

        if( (pult_1_keys & (1 << i)) != (pult_1_keys2 & (1 << i)) ){
          if (!(pult_1_keys2 & (1 << i))) {
            int send_state = -1;
            do send_state = keyboard.write(keys_pult_1_c[i]);
            while(send_state < 0);
          } else {
            int send_state = -1;
            do {
              send_state = keyboard.write(0xF0);
              send_state += keyboard.write(keys_pult_1_c[i]);
            }
            while(send_state < 0);
          }
        }

        if( (pult_2_keys & (1 << i)) != (pult_2_keys2 & (1 << i)) ){
          if (!(pult_2_keys2 & (1 << i))) {
            int send_state = -1;
            do send_state = keyboard.write(keys_pult_2_c[i]);
            while(send_state < 0);
          } else {
            int send_state = -1;
            do {
              send_state = keyboard.write(0xF0);
              send_state += keyboard.write(keys_pult_2_c[i]);
            }
            while(send_state < 0);
          }
        }
      }

      pult_1_keys = pult_1_keys2;
      pult_2_keys = pult_2_keys2;

  }

}

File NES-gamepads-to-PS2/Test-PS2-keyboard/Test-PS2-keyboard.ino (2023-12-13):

#include <PS2KeyAdvanced.h>

/* Keyboard constants  Change to suit your Arduino
   define pins used for data and clock from keyboard */
#define DATAPIN 4
#define IRQPIN  2

uint16_t c;

PS2KeyAdvanced keyboard;


void setup( )
{
// Configure the keyboard library
keyboard.begin( DATAPIN, IRQPIN );
Serial.begin( 9600 );
Serial.println( "PS2 Advanced Key Simple Test:" );
}


void loop( )
{
if( keyboard.available() )
  {
  // read the next key
  
  c = keyboard.read( );
  if( c > 0 )
    {
    Serial.print( "Value " );
    Serial.print( c, HEX );
    Serial.print( " - Status Bits " );
    Serial.print( c >> 8, HEX );
    Serial.print( "  Code " );
    Serial.println( c & 0xFF, HEX );
    }
  }
}

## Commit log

2023-11-17 new file: 3Dmodels/Case1.SLDPRT
    new file: 3Dmodels/Case_assembly.SLDASM
    new file: 3Dmodels/PCB_Sizif_XXS.SLDPRT
    new file: 3Dmodels/PS2_socket.SLDPRT
    modified: README.md
    new file: images/Arduino-Nano-V3_0-CH340-USB_TYPE-C.png
    new file: images/M2_5x14mm.png
    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
    [Case1.SLDPRT, Case_assembly.SLDASM, PCB_Sizif_XXS.SLDPRT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]
2023-11-17 Change 3D-assembly to link new components
    [Case_assembly.SLDASM]
2023-11-17 update 3D models - add button and textures
    [Button-nut.SLDPRT, Case1.SLDPRT, Case_assembly.SLDASM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]
2023-11-18 update 3D models - add Case2 and fitings, change Readme file
    [Case1.SLDPRT, Case2.SLDPRT, Case_assembly.SLDASM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]
2023-11-19 update 3D models - remove Nuts and M2.5x14 Screw (unification reason), change Readme file
    [Case1.SLDPRT, Case_assembly.SLDASM, M2_5-Nut.SLDPRT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]
2023-11-19 update 3D models - Add layout for Arduino Nano and Sega NES Slots
    [Case1.SLDPRT, Case2.SLDPRT, Case_assembly.SLDASM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]
2023-11-19 update 3D models - add Arduino Nanp holder, update readme file - links
    [Case1.SLDPRT, Case2.SLDPRT, Case_assembly.SLDASM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]
2023-11-20 update 3D models - add holes for NES slot, add first test code for NES control
    [Case1.SLDPRT, Case_assembly.SLDASM, D-SUB_9.SLDPRT]
2023-11-20 update components list
    [Case1.STL]
2023-11-20 update readme - new button component with LED
2023-11-26 change case 1 model - NES holes, Add Wire Diagram
    [Case1.SLDPRT, Case1.STL]
2023-11-27 change Wire Diagram
2023-11-29 Add resistor into wire diagram
2023-12-04 Add NES Gamepad 3D Model, improove geometry
    [Case1.SLDPRT, Case1.STL, Case_assembly.SLDASM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]
2023-12-04 Add final geometry version to 3D print
    [Case2.SLDPRT, Case_assembly.SLDASM, NES-Fix.SLDPRT]
2023-12-05 final 3d model
    [Case1.SLDPRT, Case1.STL, Case2.STL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]
2023-12-10 Final geometry tuning
    [Case1.SLDPRT, Case1.STL, Case_assembly.SLDASM]
2023-12-11 redesign wire diagram to use standard libs for Arduino, add info
    [NES-gamepads-to-PS2.ino, Test-PS2-keyboard.ino, Test-keyboard-emulator.ino]
2023-12-14 fix repeat keys bug, now working good
    [NES-gamepads-to-PS2.ino]
2023-12-15 bug fix for second Gamepad keys
    [NES-gamepads-to-PS2.ino]
